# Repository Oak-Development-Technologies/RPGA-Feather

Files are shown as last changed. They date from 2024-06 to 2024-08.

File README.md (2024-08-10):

<image src="/images/RPGA_Feather_Banner.jpeg">

# RPGA-Feather

Welcome to the RPGA Feather GitHub page. This page is designed to be a single source of truth for this board, including board files like schematics, production files, BOM, and more. In addition to that, there are also a handful of examples available to build with just a little effort specifically for the RPGA Feather.

Continue reading to get started.

# Getting Started

What is the RPGA Feather? RPGA Feather is a development board which provides the ease of use of the RP2040 from Raspberry Pi with the wide open source support of the iCE40 FPGA line. RPGA Feather combines the RP2040 with an iCE5LP4K FPGA from Lattice Semiconductor which has 3520 LUTs, 2 hardware SPI and I2C blocks, a bright RGB LED driver, two internal oscillators, and 1 PLL which can be used to generate additional clocks for your designs.

RPGA Feather provides up to 11 direct GPIO connected between the RP2040 and the iCE5LP4K. This includes the 3 pins used for programming the bitstream onto the FPGA.

Having a good pinout guide can be useful for getting started. We provide this pinout card with every RPGA Feather purchased from our shop.

<image src="/images/RPGA%20Feather%20rev%20b.jpg">

You can find the PDF under the [Hardware Directory Here](/hardware/RPGA.pdf). Thanks to [@skliffmueller](https://github.com/skliffmueller) for making and sharing it.

### usage examples

We provide a few examples in this repository for getting familiar with interfacing with the iCE5LP4K FPGA.

Following the comments in the [top.v](/src/top.v) file under the `src` directory can enable you to build these specific examples quickly. Once you have the example set up in the file, you can build it using the following command:

```make
make build
```

Building requires using Yosys OSS CAD Suite, which can be found by visiting the [OSS CAD Suite build github repository](https://github.com/YosysHQ/oss-cad-suite-build). Follow the instructions for setting up the tools on your OS and you'll be good to go.

Once you have a `top.bin` file which should be in the base directory of the repository, you can simply copy it over onto your RPGA Feather `CIRCUITPY` drive. If you haven't downloaded the CircuitPython Community Bundle to get IcePython you can [head to the CircuitPython Libraries page](https://circuitpython.org/libraries) to download it, or [download the latest release directly](https://github.com/skerr92/Oakdevtech_CircuitPython_IcePython/releases).

Once you have IcePython and the `top.bin` file loaded onto your RPGA Feather, the next step is to get your code setup to load the FPGA.

Using Mu or your favorite CircuitPython compatible IDE, open up the `code.py` file and past the following code:

```py
# SPDX-FileCopyrightText: 2017 Scott Shawcroft, written for Adafruit Industries
# SPDX-FileCopyrightText: Copyright (c) 2023 Seth Kerr for Oak Development Technologies
#
# SPDX-License-Identifier: Unlicense

"""
Example showing how to program an iCE40 FPGA with circuitpython!
"""

import time
import board, busio
import oakdevtech_icepython
import gc

print("Mem Free: ",gc.mem_free(),"Mem Alloc", gc.mem_alloc())
spi = busio.SPI(clock=board.F_SCK, MOSI=board.F_MOSI, MISO=board.F_MISO)

iceprog = oakdevtech_icepython.Oakdevtech_icepython(
    spi, board.F_CSN, board.F_RST, "top.bin"
)

timestamp = time.monotonic()

iceprog.program_fpga()

endstamp = time.monotonic()
print("done in: ", (endstamp - timestamp), "seconds")

print("done")
```
Save the file and you should see the green CDONE LED light up on your board. Depending on the example you built, you might see the RGB LED light up that is next to the FPGA.

### Questions?

If you have any questions, please feel free to open an issue. Issues are a great way to raise concerns or bugs with the examples or hardware itself. And your feedback is critical to making sure we can fix issues and improve the quality of life for everyone's experience with RPGA Feather.

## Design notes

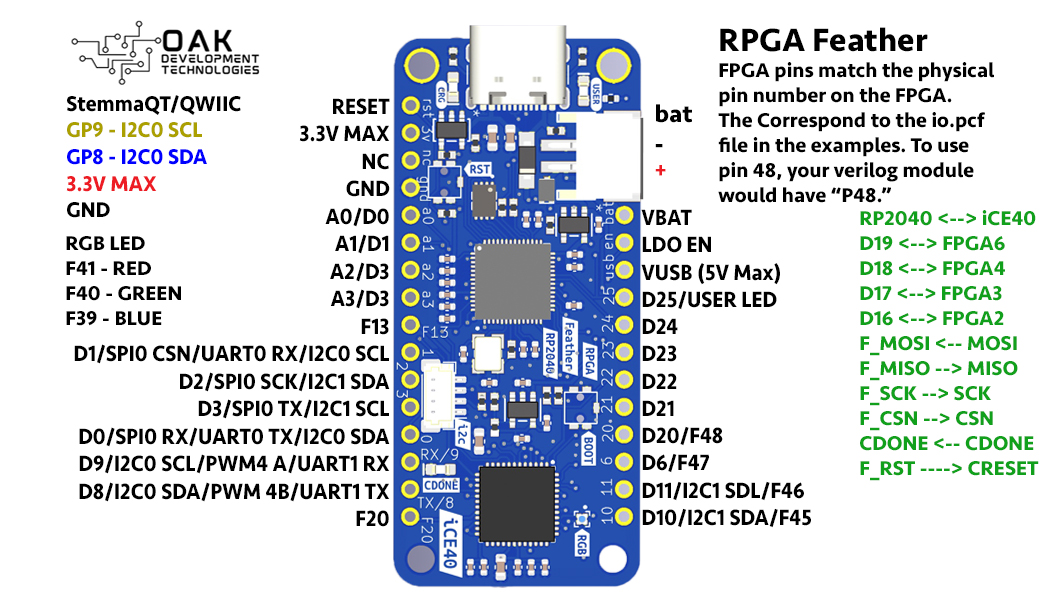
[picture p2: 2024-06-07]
images/RPGA Feather rev b.jpg

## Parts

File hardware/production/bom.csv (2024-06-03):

Designator | Footprint | Quantity | Value | LCSC Part #
C1, C2 | 0402 | 2 | 27p
C10, C11, C12, C13, C14, C17, C18, C23, C24, C25, C26, C4, C5, C7, C8, C9 | 0402 | 16 | 0.1u
C15, C20 | 0402 | 2 | 0.47u
C16, C19, C3, C6 | 0402 | 4 | 1u
C21, C22, C27, C28 | 0603 | 4 | 4.7u
CDONE0 | LED-0603 | 1 | GREEN
CHG0 | LED-0603 | 1 | LED0603
D1 | LED_UHD1110-FKA-CL1A13R3Q1BBQFMF3 | 1 | UHD1110-FKA-CL1A13R3Q1BBQFMF3
J1 | USB_C_Receptacle_GCT_USB4105-xx-A_16P_TopMnt_Horizontal | 1 | USB_C_Receptacle_USB2.0_14P
J2 | JST-2-SMD | 1 | CONN_02-JST-2MM-SMT
J3 | JST_SH_BM04B-SRSS-TB_1x04-1MP_P1.00mm_Vertical | 1 | SM04B-SRSS-TB_LF__SN_
JP1, JP2, JP3, JP4 | SMT-JUMPER_3_1-NC_TRACE_SILK | 4 | JUMPER-SMT_3_1-NC_TRACE_SILK
R1, R10, R15, R7 | R0402 | 4 | 10k
R11 | R0402 | 1 | 953
R12 | R0402 | 1 | R-US_R0402
R13, R14, R4, R5 | R0402 | 4 | 5k1
R16 | 0402 | 1 | 2k
R2, R6 | R0402 | 2 | 1k
R3 | R0402 | 1 | 100k
R8, R9 | R0402 | 2 | 27
U$1 | FEATHER_PINS | 1 | FEATHER_BASE
U$2 | SOD3716X117(SOD-123) | 1 | MBR0520LT1G
U$3 | QFN-56 | 1 | RP2040_M0+
U$4, U$5 | 3.3X2.9 | 2 | SOF-232HST
U1 | X2-DFN2015-3 | 1 | DMG3415U-7X2-DFN2015-3
U2 | SOT-23-5_MC-L | 1 | MCP73831T-2ACI/OTSOT-23-5_MC-L
U3 | DBV5-L | 1 | TPS73201DBVRDBV5-L
U4 | DBV5_TEX-L | 1 | TLV75533PDBVRDBV5_TEX-L
U6 | QFN50P700X700X100-49N | 1 | ICE5LP1K-SG48ITR
U7 | W25Q16JVUXIQ_WIN-L | 1 | W25Q16JVUXIQW25Q16JVUXIQ_WIN-L
USER1 | LED-0603 | 1 | USER
Y1 | XTAL_ECS-327ATQMV-AS-TR | 1 | ECS-327ATQMV-AS-TR

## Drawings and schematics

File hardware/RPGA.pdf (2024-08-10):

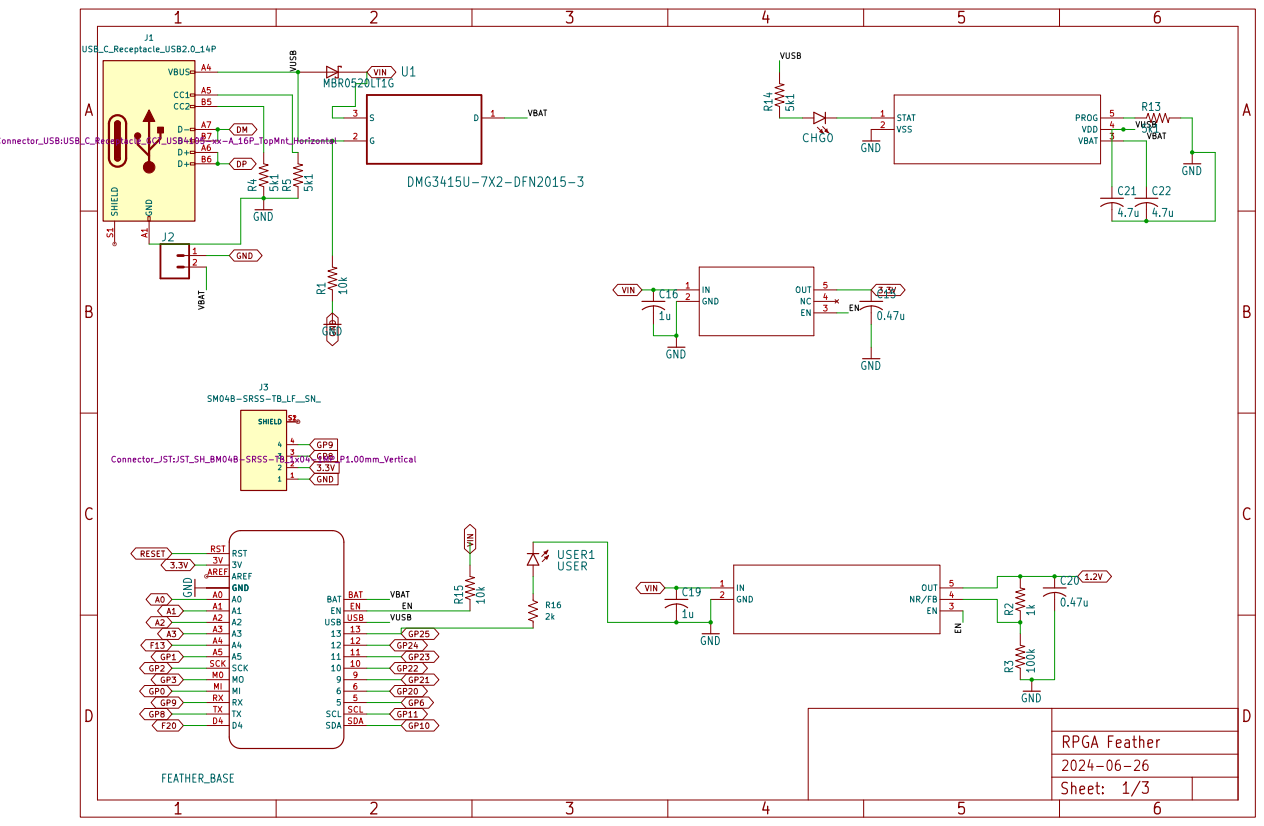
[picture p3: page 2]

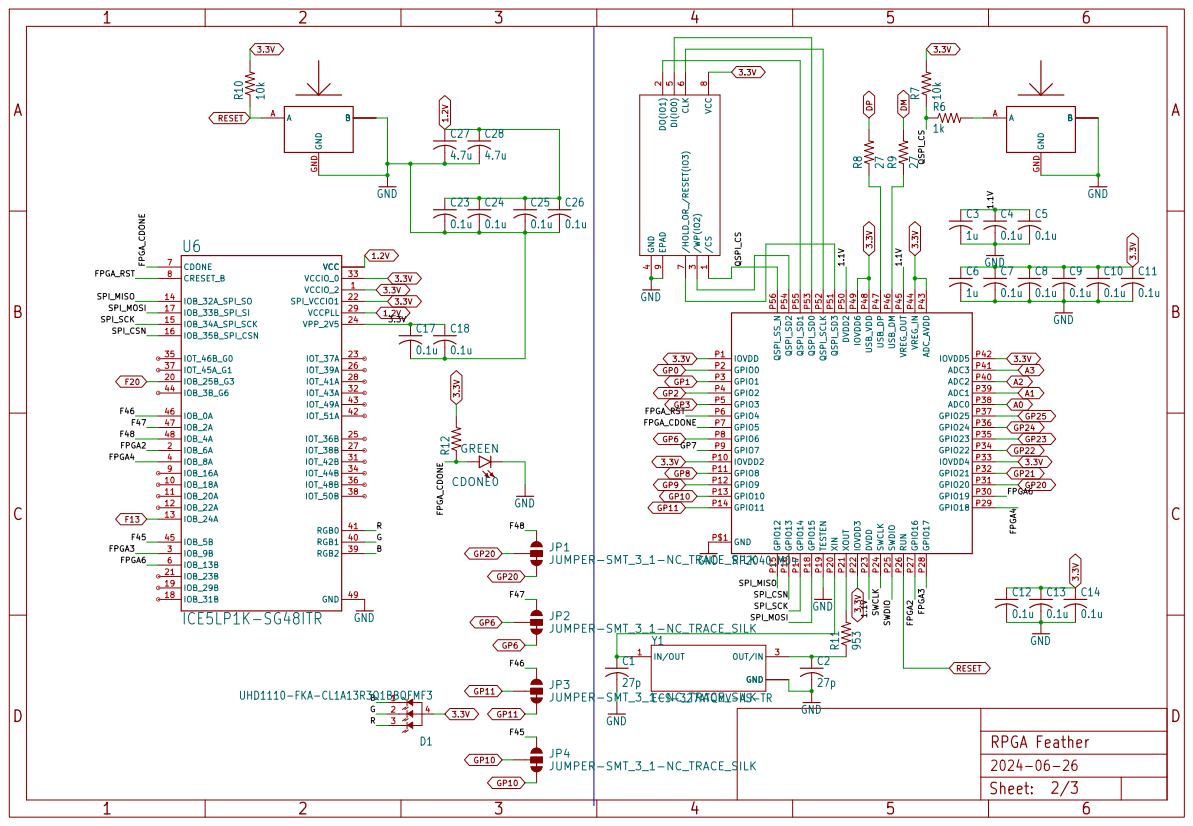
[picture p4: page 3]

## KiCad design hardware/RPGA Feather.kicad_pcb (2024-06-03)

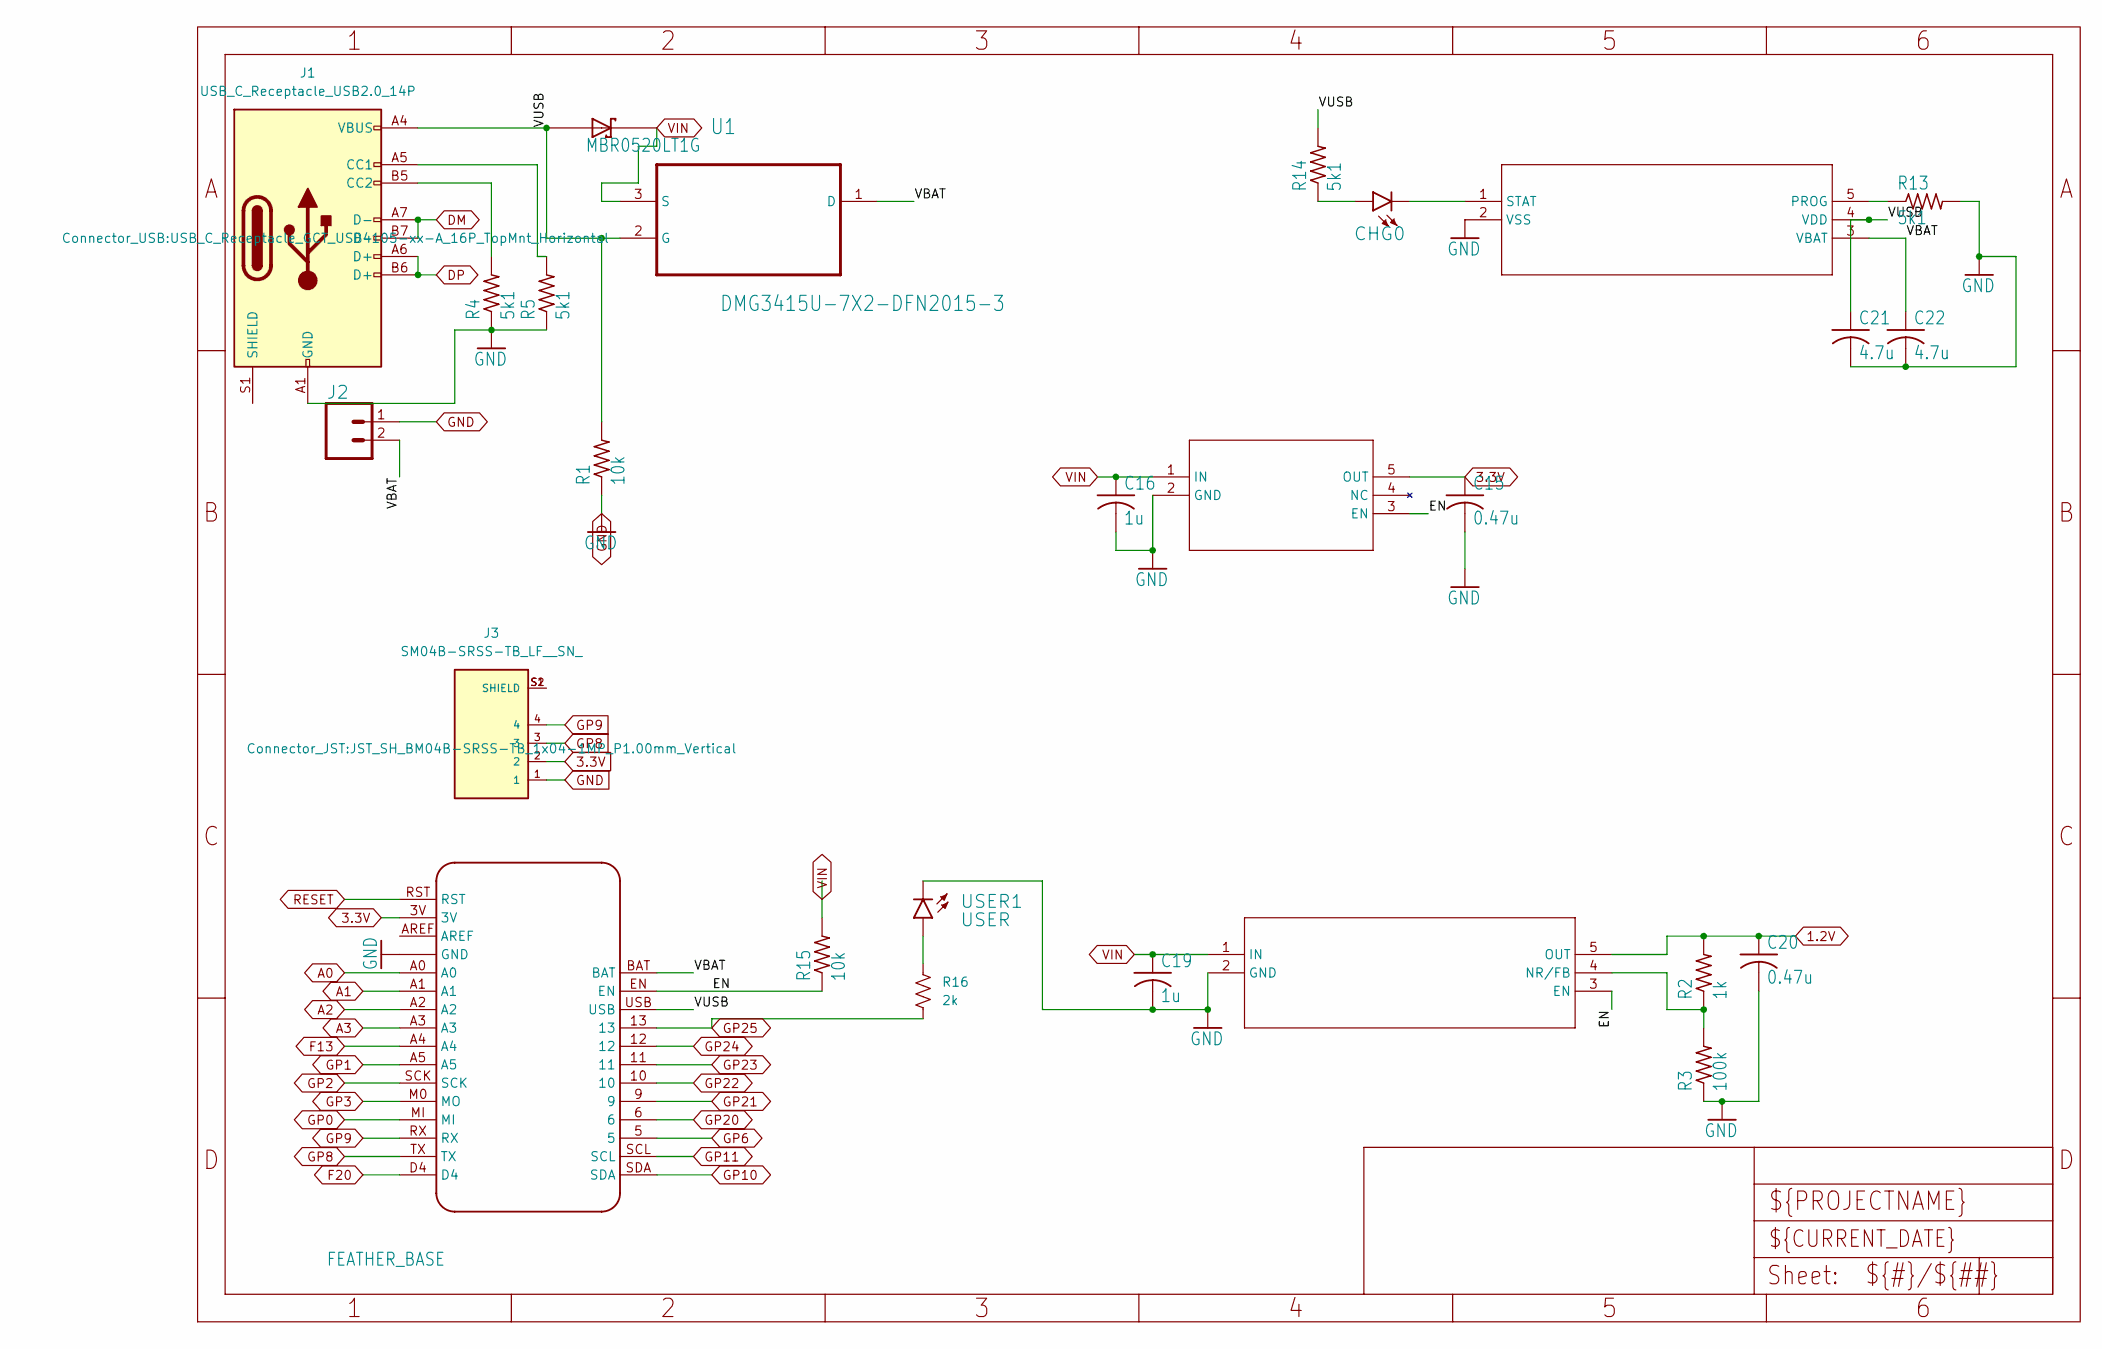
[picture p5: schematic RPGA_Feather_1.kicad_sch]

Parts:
C15, C20: 0.47u; C_0402_1005Metric
C16, C19: 1u; C_0402_1005Metric
C21, C22: 4.7u; C_0603_1608Metric
CHG0: LED0603; LED-0603
J1: USB_C_Receptacle_USB2.0_14P; USB_C_Receptacle_GCT_USB4105-xx-A_16P_TopMnt_Horizontal
J2: CONN_02-JST-2MM-SMT; JST-2-SMD
J3: SM04B-SRSS-TB_LF__SN_; JST_SH_BM04B-SRSS-TB_1x04-1MP_P1.00mm_Vertical
R1, R15: 10k; R0402
R2: 1k; R0402
R3: 100k; R0402
R4, R5, R13, R14: 5k1; R0402
R16: 2k; R_0402_1005Metric
U1: DMG3415U-7X2-DFN2015-3; X2-DFN2015-3
U2: MCP73831T-2ACI/OTSOT-23-5_MC-L; SOT-23-5_MC-L
U3: TPS73201DBVRDBV5-L; DBV5-L
U4: TLV75533PDBVRDBV5_TEX-L; DBV5_TEX-L
U$1: FEATHER_BASE; FEATHER_PINS
U$2: MBR0520LT1G; SOD3716X117(SOD-123)
USER1: USER; LED-0603

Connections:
1.2V: C20.1, R2.2, U3.5 (OUT); also elsewhere on the board
3.3V: C15.1, J3.2, U4.5 (OUT), U$1.3V; also elsewhere on the board
/RPGA Feather_1/EN: R15.1, U3.3 (EN), U4.3 (EN), U$1.EN
/RPGA Feather_1/VBAT: C22.1, J2.2 (1), U1.1 (D), U2.3 (VBAT), U$1.BAT
/RPGA Feather_1/VUSB: C21.1, J1.A4 (VBUS), J1.A9 (VBUS), J1.B4 (VBUS), J1.B9 (VBUS), R1.2, R14.2, U1.2 (G), U2.4 (VDD), U$1.USB, U$2.2 (A)
A0: U$1.A0; also elsewhere on the board
A1: U$1.A1; also elsewhere on the board
A2: U$1.A2; also elsewhere on the board
A3: U$1.A3; also elsewhere on the board
DM: J1.A7 (D-), J1.B7 (D-); also elsewhere on the board
DP: J1.A6 (D+), J1.B6 (D+); also elsewhere on the board
F13: U$1.A4; also elsewhere on the board
F20: U$1.D4; also elsewhere on the board
GND: C15.2, C16.2, C19.2, C20.2, C21.2, C22.2, J1.A1 (GND), J1.A12 (GND), J1.B1 (GND), J1.B12 (GND), J2.1 (2), J3.1, R1.1, R3.1, R4.1, R5.1, R13.2, U2.2 (VSS), U3.2 (GND), U4.2 (GND), U$1.GND, U$1.P$1 (GND), U$1.P$2 (GND), USER1.C; also elsewhere on the board
GP0: U$1.MI; also elsewhere on the board
GP1: U$1.A5; also elsewhere on the board
GP2: U$1.SCK; also elsewhere on the board
GP3: U$1.M0 (MO); also elsewhere on the board
GP6: U$1.5; also elsewhere on the board
GP8: J3.3, U$1.TX; also elsewhere on the board
GP9: J3.4, U$1.RX; also elsewhere on the board
GP10: U$1.SDA; also elsewhere on the board
GP11: U$1.SCL; also elsewhere on the board
GP20: U$1.6; also elsewhere on the board
GP21: U$1.9; also elsewhere on the board
GP22: U$1.10; also elsewhere on the board
GP23: U$1.11; also elsewhere on the board
GP24: U$1.12; also elsewhere on the board
GP25: R16.2, U$1.13; also elsewhere on the board
unnamed: CHG0.A, R14.1
unnamed: J1.A5 (CC1), R5.2
unnamed: J1.B5 (CC2), R4.2
unnamed: R16.1, USER1.A
unnamed: R13.1, U2.5 (PROG)
unnamed: CHG0.C, U2.1 (STAT)
unnamed: R2.1, R3.2, U3.4 (NR/FB)
RESET: U$1.RST; also elsewhere on the board
VIN: C16.1, C19.1, R15.2, U1.3 (S), U3.1 (IN), U4.1 (IN), U$2.1 (C)

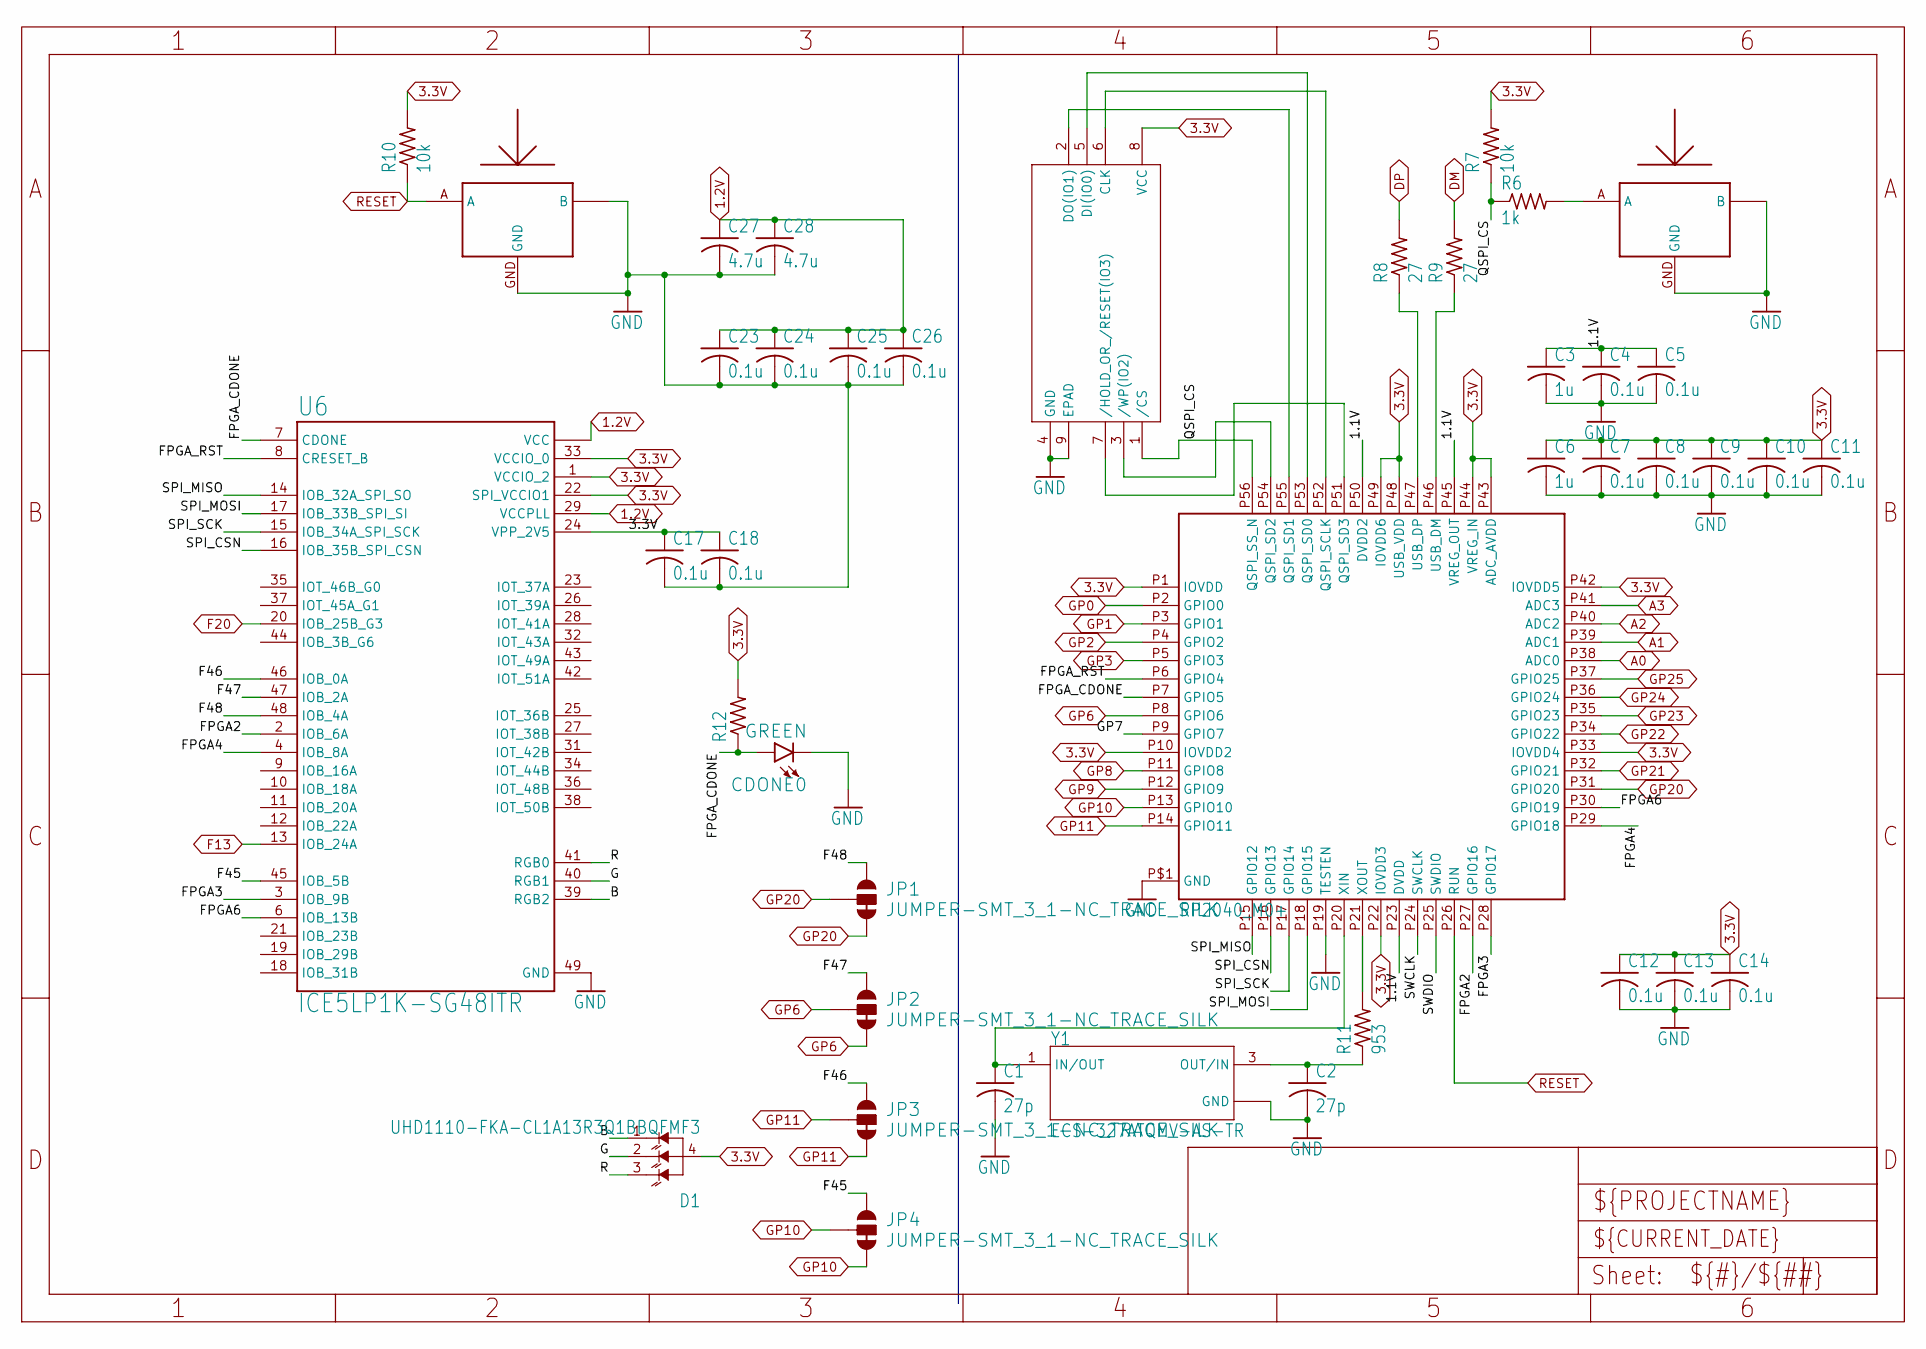
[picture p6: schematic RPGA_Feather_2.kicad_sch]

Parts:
C1, C2: 27p; C_0402_1005Metric
C3, C6: 1u; C_0402_1005Metric
C4, C5, C7, C8, C9, C10, C11, C12, C13, C14, C17, C18, C23, C24, C25, C26: 0.1u; C_0402_1005Metric
C27, C28: 4.7u; C_0603_1608Metric
CDONE0: GREEN; LED-0603
D1: UHD1110-FKA-CL1A13R3Q1BBQFMF3; LED_UHD1110-FKA-CL1A13R3Q1BBQFMF3
JP1, JP2, JP3, JP4: JUMPER-SMT_3_1-NC_TRACE_SILK; SMT-JUMPER_3_1-NC_TRACE_SILK
R6: 1k; R0402
R7, R10: 10k; R0402
R8, R9: 27; R0402
R11: 953; R0402
R12: R-US_R0402; R0402
U6: ICE5LP1K-SG48ITR; QFN50P700X700X100-49N
U7: W25Q16JVUXIQW25Q16JVUXIQ_WIN-L; W25Q16JVUXIQ_WIN-L
U$3: RP2040_M0+; QFN-56
U$4, U$5: SOF-232HST; 3.3X2.9
Y1: ECS-327ATQMV-AS-TR; XTAL_ECS-327ATQMV-AS-TR

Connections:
1.2V: C23.1, C24.1, C25.1, C26.1, C27.1, C28.1, U6.5 (VCC), U6.29 (VCCPLL), U6.30 (VCC); also elsewhere on the board
3.3V: C6.1, C7.1, C8.1, C9.1, C10.1, C11.1, C12.1, C13.1, C14.1, C17.1, C18.1, D1.4 (ANODE), R7.2, R10.2, R12.2, U6.1 (VCCIO_2), U6.22 (SPI_VCCIO1), U6.24 (VPP_2V5), U6.33 (VCCIO_0), U7.8 (VCC), U$3.P1 (IOVDD), U$3.P10 (IOVDD2), U$3.P22 (IOVDD3), U$3.P33 (IOVDD4), U$3.P42 (IOVDD5), U$3.P43 (ADC_AVDD), U$3.P44 (VREG_IN), U$3.P48 (USB_VDD), U$3.P49 (IOVDD6); also elsewhere on the board
/RPGA Feather_2/1.1V: C3.1, C4.1, C5.1, U$3.P23 (DVDD), U$3.P45 (VREG_OUT), U$3.P50 (DVDD2)
/RPGA Feather_2/B: D1.1 (BLUE), U6.39 (RGB2)
/RPGA Feather_2/F45: JP4.1, U6.45 (IOB_5B)
/RPGA Feather_2/F46: JP3.1, U6.46 (IOB_0A)
/RPGA Feather_2/F47: JP2.1, U6.47 (IOB_2A)
/RPGA Feather_2/F48: JP1.1, U6.48 (IOB_4A)
/RPGA Feather_2/FPGA2: U6.2 (IOB_6A), U$3.P27 (GPIO16)
/RPGA Feather_2/FPGA3: U6.3 (IOB_9B), U$3.P28 (GPIO17)
/RPGA Feather_2/FPGA4: U6.4 (IOB_8A), U$3.P29 (GPIO18)
/RPGA Feather_2/FPGA6: U6.6 (IOB_13B), U$3.P30 (GPIO19)
/RPGA Feather_2/FPGA_CDONE: CDONE0.A, R12.1, U6.7 (CDONE), U$3.P7 (GPIO5)
/RPGA Feather_2/FPGA_RST: U6.8 (CRESET_B), U$3.P6 (GPIO4)
/RPGA Feather_2/G: D1.2 (GREEN), U6.40 (RGB1)
/RPGA Feather_2/GP7: U$3.P9 (GPIO7)
/RPGA Feather_2/QSPI_CS: R6.1, R7.1, U7.1 (/CS), U$3.P56 (QSPI_SS_N)
/RPGA Feather_2/R: D1.3 (RED), U6.41 (RGB0)
/RPGA Feather_2/SPI_CSN: U6.16 (IOB_35B_SPI_CSN), U$3.P16 (GPIO13)
/RPGA Feather_2/SPI_MISO: U6.14 (IOB_32A_SPI_SO), U$3.P15 (GPIO12)
/RPGA Feather_2/SPI_MOSI: U6.17 (IOB_33B_SPI_SI), U$3.P18 (GPIO15)
/RPGA Feather_2/SPI_SCK: U6.15 (IOB_34A_SPI_SCK), U$3.P17 (GPIO14)
/RPGA Feather_2/SWCLK: U$3.P24 (SWCLK)
/RPGA Feather_2/SWDIO: U$3.P25 (SWDIO)
A0: U$3.P38 (ADC0); also elsewhere on the board
A1: U$3.P39 (ADC1); also elsewhere on the board
A2: U$3.P40 (ADC2); also elsewhere on the board
A3: U$3.P41 (ADC3); also elsewhere on the board
DM: R9.2; also elsewhere on the board
DP: R8.2; also elsewhere on the board
F13: U6.13 (IOB_24A); also elsewhere on the board
F20: U6.20 (IOB_25B_G3); also elsewhere on the board
GND: C1.2, C2.2, C3.2, C4.2, C5.2, C6.2, C7.2, C8.2, C9.2, C10.2, C11.2, C12.2, C13.2, C14.2, C17.2, C18.2, C23.2, C24.2, C25.2, C26.2, C27.2, C28.2, CDONE0.C, U6.49 (GND), U7.4 (GND), U7.9 (EPAD), U$3.P19 (TESTEN), U$3.P$1 (GND), U$4.B, U$4.B2 (B), U$4.B3 (B), U$4.GND, U$5.B, U$5.B2 (B), U$5.B3 (B), U$5.GND, Y1.2 (GND), Y1.4 (GND); also elsewhere on the board
GP0: U$3.P2 (GPIO0); also elsewhere on the board
GP1: U$3.P3 (GPIO1); also elsewhere on the board
GP2: U$3.P4 (GPIO2); also elsewhere on the board
GP3: U$3.P5 (GPIO3); also elsewhere on the board
GP6: JP2.2, JP2.3, U$3.P8 (GPIO6); also elsewhere on the board
GP8: U$3.P11 (GPIO8); also elsewhere on the board
GP9: U$3.P12 (GPIO9); also elsewhere on the board
GP10: JP4.2, JP4.3, U$3.P13 (GPIO10); also elsewhere on the board
GP11: JP3.2, JP3.3, U$3.P14 (GPIO11); also elsewhere on the board
GP20: JP1.2, JP1.3, U$3.P31 (GPIO20); also elsewhere on the board
GP21: U$3.P32 (GPIO21); also elsewhere on the board
GP22: U$3.P34 (GPIO22); also elsewhere on the board
GP23: U$3.P35 (GPIO23); also elsewhere on the board
GP24: U$3.P36 (GPIO24); also elsewhere on the board
GP25: U$3.P37 (GPIO25); also elsewhere on the board
unnamed: R6.2, U$5.A
unnamed: U7.6 (CLK), U$3.P52 (QSPI_SCLK)
unnamed: U7.5 (DI(IO0)), U$3.P53 (QSPI_SD0)
unnamed: U7.2 (DO(IO1)), U$3.P55 (QSPI_SD1)
unnamed: U7.3 (/WP(IO2)), U$3.P54 (QSPI_SD2)
unnamed: U7.7 (/HOLD_OR_/RESET(IO3)), U$3.P51 (QSPI_SD3)
unnamed: R9.1, U$3.P46 (USB_DM)
unnamed: R8.1, U$3.P47 (USB_DP)
unnamed: C1.1, U$3.P20 (XIN), Y1.1 (IN/OUT)
unnamed: R11.2, U$3.P21 (XOUT)
unnamed: C2.1, R11.1, Y1.3 (OUT/IN)
RESET: R10.1, U$3.P26 (RUN), U$4.A; also elsewhere on the board

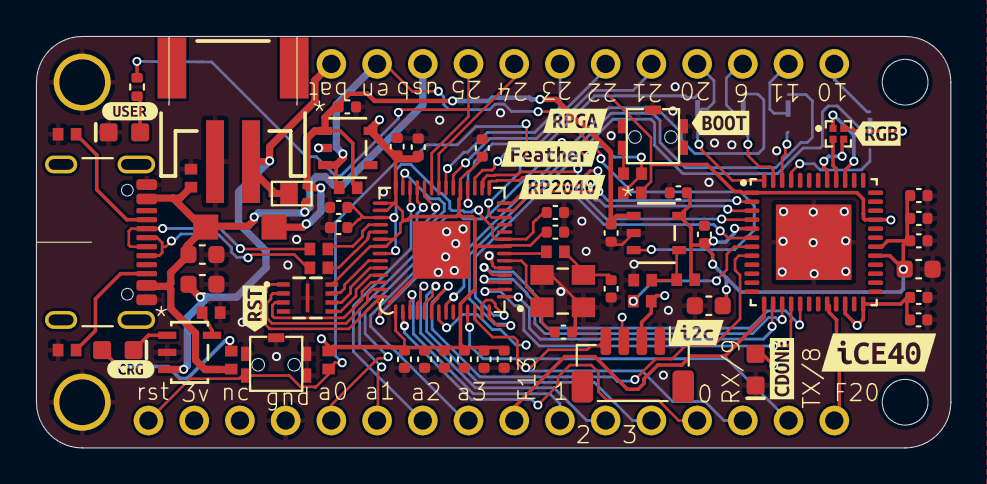
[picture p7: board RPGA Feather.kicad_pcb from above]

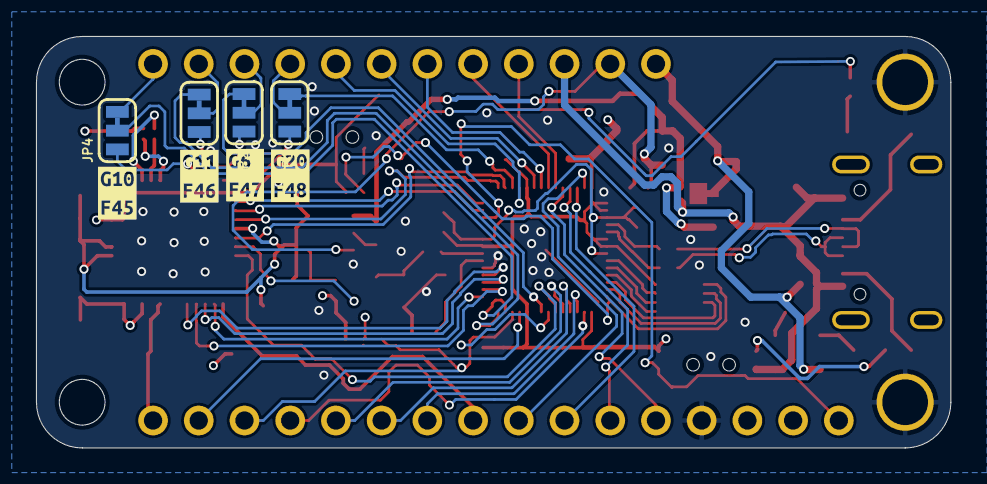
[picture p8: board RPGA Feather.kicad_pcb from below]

Board: 4 copper layers, 50.8 x 22.9 mm, 82 parts (8 on the bottom side), 68 nets.

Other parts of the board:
kibuzzard-6601CD6F: G***; kibuzzard-6601CD6F
kibuzzard-6601CD49: G***; kibuzzard-6601CD49
kibuzzard-6601CDB5: G***; kibuzzard-6601CDB5
kibuzzard-6601CDBD: G***; kibuzzard-6601CDBD
kibuzzard-6601FC5E: G***; kibuzzard-6601FC5E
kibuzzard-6601FC9E: G***; kibuzzard-6601FC9E
kibuzzard-6601FC47: G***; kibuzzard-6601FC47
kibuzzard-6601FCCE: G***; kibuzzard-6601FCCE
kibuzzard-6601FCEA: G***; kibuzzard-6601FCEA
kibuzzard-6601FCFE: G***; kibuzzard-6601FCFE
kibuzzard-6601FD10: G***; kibuzzard-6601FD10
kibuzzard-66565BE9: G***; kibuzzard-66565BE9
kibuzzard-660226BE: G***; kibuzzard-660226BE
kibuzzard-6657261C: G***; kibuzzard-6657261C
kibuzzard-66022711: G***; kibuzzard-66022711

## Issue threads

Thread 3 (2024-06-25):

Schematic

develone, 2024-06-25:
Can you add pdf of schematic.

skliffmueller, 2024-06-27:
This should get you started

[RPGA.pdf](https://github.com/user-attachments/files/16004084/RPGA.pdf)

skerr92, 2024-08-10:
Thanks @skliffmueller for sharing that PDF, I'll add it and credit you.

skerr92, 2024-08-10:
Added to the README on the main page of the repo. Thanks!

Closed 2024-08-10.

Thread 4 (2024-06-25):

kicad problems

develone, 2024-06-25:
Drawing sheet 'empty.kicad_wks' not found. Error loading the symbol library table. Running kicad  This is kicad ver  6.0.8 on Raspberry Pi 4 running bullseye. Raspberry Pi 5 bookworm does not work at all.

skliffmueller, 2024-06-26:
I use Windows 11, KiCad 8.0.3 with no issues. Might be specific to the version or architecture you are using.
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

skerr92, 2024-08-10:
I'm not sure what would cause backwards compatibility issues with KiCAD 6. I use KiCAD 8.0 release build. You might check ask on the KiCAD forums/discussion if others have had issues opening on KiCAD 6 running on Raspberry Pi

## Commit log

2024-06-03 add hardware files
    [RPGA Feather.kicad_pcb, RPGA Feather.kicad_sch, RPGA_Feather_1.kicad_sch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]
2024-08-10 PDF of RPGA Feather Schematic
2024-08-10 Update README.md
    add pdf of schematic
